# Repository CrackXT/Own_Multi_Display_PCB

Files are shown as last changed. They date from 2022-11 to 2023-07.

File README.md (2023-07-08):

# Own_Multi_Display_PCB

PCB files for Multi Display Board

# Description

This board serves as a development platform for finished devices with different display sizes.

- MiP 2,7" https://www.adafruit.com/product/4694
- TFT IPS 1,9" https://www.adafruit.com/product/5394
- TFT IPS 1,69" https://www.adafruit.com/product/5206
- TFT IPS 1,47" https://www.adafruit.com/product/5393

With a programmable status LED (RGB, SK6812-E) and an ambient light sensor (analogue, ALS-PT19) to regulate the brightness of TFT screens.

The screen, LED and ambient light sensor can be controlled via the existing Featherformat socket and the MCU used in it.

The board can be produced here (AISLER) with the files (.brd and .sch) or by any other PCB manufacturer. -> https://aisler.net/

# Serie

- .dev

# Layout

Top<br>
Multi_Display_Top

Bottom<br>
Multi_Display_Bottom

Routing/Dimensions(inch)<br>
Multi_Display_v1 0

Schematic<br>
Schematic as .pdf at the top of the page.

# License

Open hardware, use it, mod it, whatever you want, feel free...

# Thanks!

Own design and layout.

# Version - Build

v1.0 - 05.11.2022

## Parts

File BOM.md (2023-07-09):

# BOM - List

part list for Use

# sensor
1x ALS-PT19 (Anlog) https://www.digikey.de/de/products/detail/everlight-electronics-co-ltd/ALS-PT19-315C-L177-TR8/2675735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

# led
1x SK6812MINI-E 3535 https://eckstein-shop.de/OPSCO10xRGBLEDwithICSK6812SMD35284PINSK6812MINI-E-10

# resistor
1x 100kOhm 0805 https://www.reichelt.de/dk/de/smd-widerstand-0805-100-kohm-0-1-tk25-125-mw-spr-0805-100k-p123367.html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

# capacitor
2x 0,1µF 0805 https://www.reichelt.de/dk/de/smd-vielschichtkondensator-g0805-1-0-f-25v-x7r-g0805-1-0-25-p89730.html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

# socket strips
1x 1X4 https://www.reichelt.de/buchsenleiste-2-54mm-1x4-gerade-bkl-10120946-p266671.html?&trstct=pol_0&nbc=1<br>

1x 1X9<br>
- 1x 1X4 https://www.reichelt.de/buchsenleiste-2-54mm-1x4-gerade-bkl-10120946-p266671.html?&trstct=vrt_pdn&nbc=1<br>
- 1x 1X5 https://www.reichelt.de/buchsenleiste-2-54mm-1x5-gerade-bkl-10120947-p266672.html?&trstct=vrt_pdn&nbc=1<br>

3x 1X11<br>
- 3x 1X5 https://www.reichelt.de/buchsenleiste-2-54mm-1x5-gerade-bkl-10120947-p266672.html?&trstct=vrt_pdn&nbc=1<br>
- 3x 1X6 https://www.reichelt.de/buchsenleiste-2-54mm-1x6-gerade-bkl-10120948-p266673.html?&trstct=vrt_pdn&nbc=1<br>

1x 1X12 https://www.reichelt.de/buchsenleiste-2-54mm-1x12-gerade-bkl-10120951-p266676.html?&trstct=pol_1&nbc=1<br>
1x 1X16 https://www.reichelt.de/buchsenleiste-2-54mm-1x16-gerade-bkl-10120953-p266678.html?&nbc=1<br>

# button
2x APEM PHAP3363 (THT Side) https://www.conrad.de/de/p/apem-phap3363-drucktaster-12-v-dc-0-05-a-1-x-aus-ein-tastend-1-st-700310.html

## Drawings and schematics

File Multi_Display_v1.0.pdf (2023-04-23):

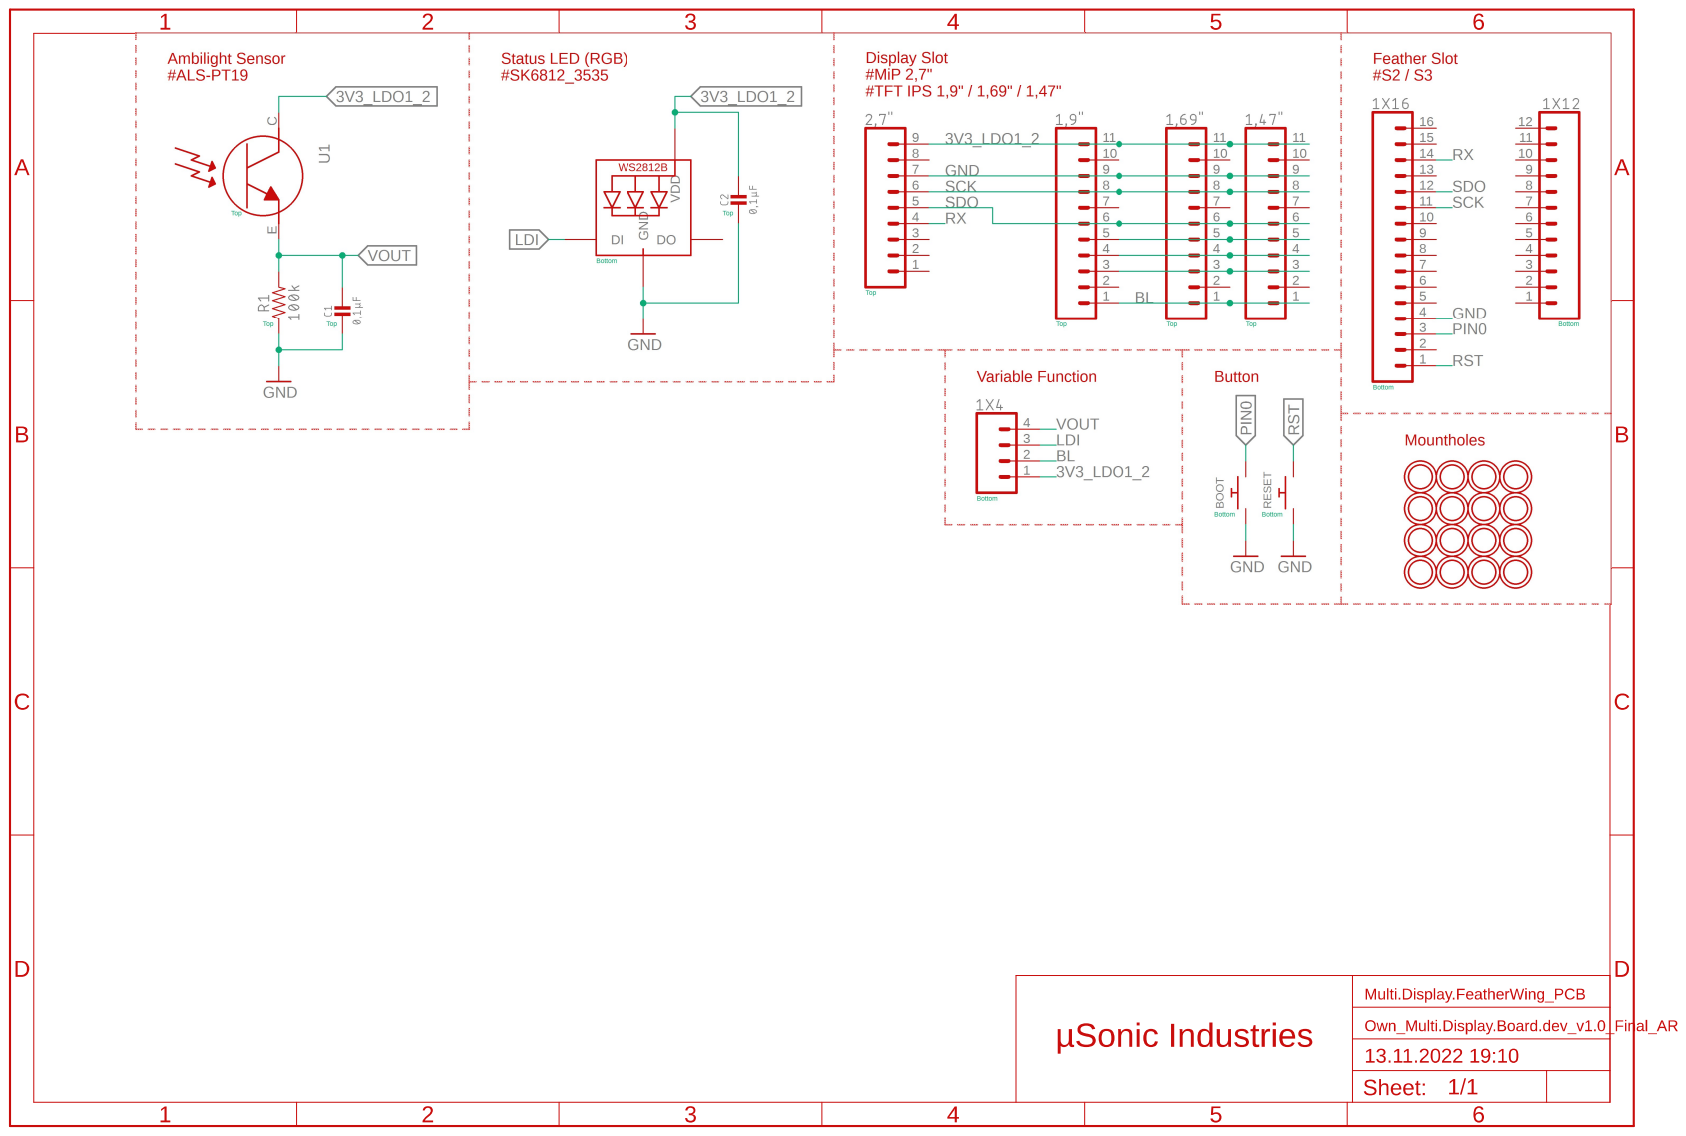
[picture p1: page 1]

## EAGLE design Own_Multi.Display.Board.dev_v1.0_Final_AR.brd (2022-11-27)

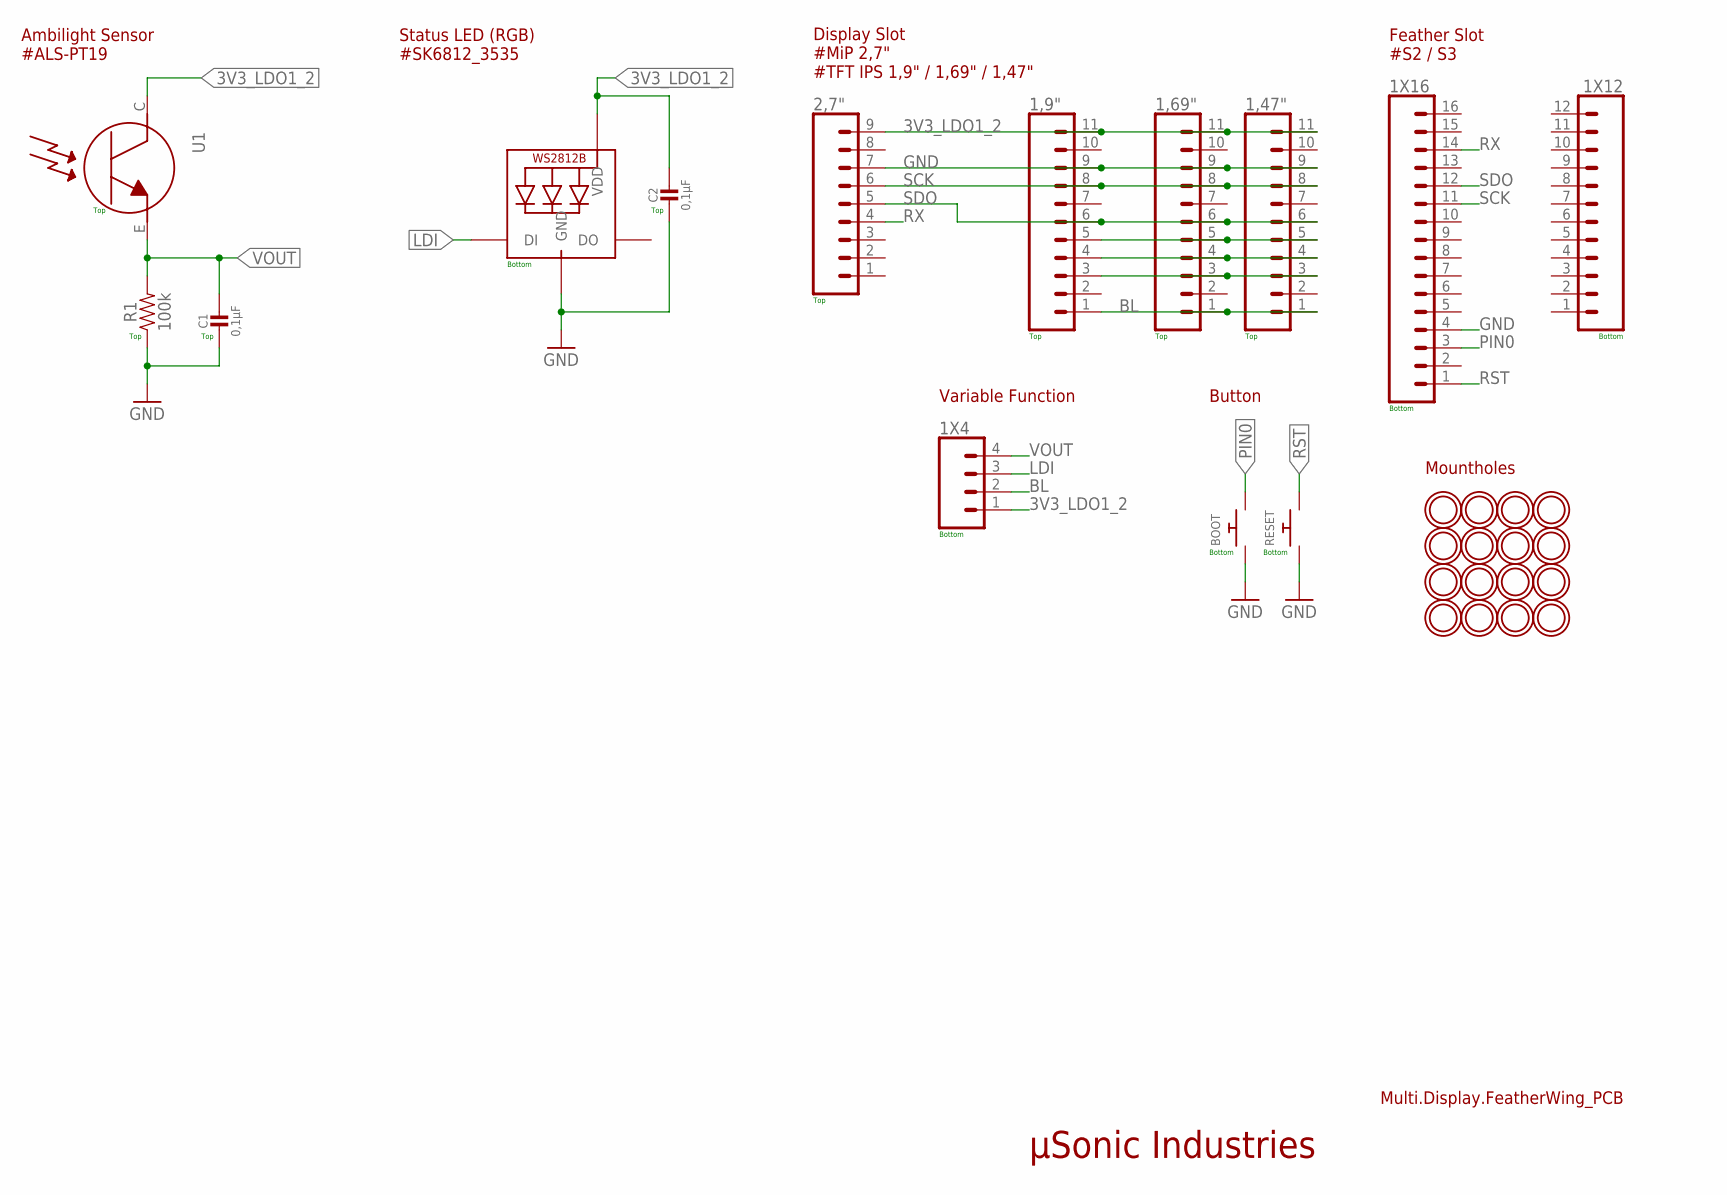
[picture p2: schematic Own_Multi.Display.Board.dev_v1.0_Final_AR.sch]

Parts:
1,9", 1,47", 1,69": CONN_111X11_NO_SILK; 1X11_NO_SILK
1X4: CONN_041X04_NO_SILK; 1X04_NO_SILK
1X12: CONN_12NO_SILK; 1X12_NO_SILK
1X16: CONN_161X16_NO_SILK; 1X16_NO_SILK
2,7": CONN_09NO_SILK; 1X09_NO_SILK
BOOT: SWITCH_PUSHBUTTONSF_OWN; OWN_TACT_PANA-EVQ
C1, C2: 0,1µF; MICROBUILDER_0805_10MGAP
LED1: MICROBUILDER_WS2812B_SK6812E; MICROBUILDER_NEO3535_REVERSE
R1: 100k; 0805
RESET: SWITCH_PUSHBUTTONSF_OWN; OWN_TACT_PANA-EVQ
U1: MICROBUILDER_LIGHT_ALS-PT19-315C; MICROBUILDER_ALS-PT19-315C
U$5, U$8, U$16, U$18, U$19, U$23, U$24, U$25, U$26, U$27, U$28, U$29, U$30, U$31, U$32, U$33: MOUNTINGHOLE2.5; MOUNTINGHOLE_2.5_PLATED

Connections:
3V3_LDO1_2: 1,9".11, 1,47".11, 1,69".11, 1X4.1, 2,7".9, C2.1, LED1.1-VDD (VDD), U1.C
BL: 1,9".1, 1,47".1, 1,69".1, 1X4.2
GND: 1,9".9, 1,47".9, 1,69".9, 1X16.4, 2,7".7, BOOT.P$1, C1.2, C2.2, LED1.3-GND (GND), R1.1, RESET.P$1
LDI: 1X4.3, LED1.4-DIN (DI)
unnamed: 1,9".5, 1,47".5, 1,69".5
unnamed: 1,9".4, 1,47".4, 1,69".4
unnamed: 1,9".3, 1,47".3, 1,69".3
PIN0: 1X16.3, BOOT.P$2
RST: 1X16.1, RESET.P$2
RX: 1X16.14, 2,7".4
SCK: 1,9".8, 1,47".8, 1,69".8, 1X16.11, 2,7".6
SDO: 1,9".6, 1,47".6, 1,69".6, 1X16.12, 2,7".5
VOUT: 1X4.4, C1.1, R1.2, U1.E

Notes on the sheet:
µSonic Industries
Multi.Display.FeatherWing_PCB
Ambilight Sensor #ALS-PT19
Mountholes
Top
Bottom
Status LED (RGB) #SK6812_3535
Display Slot #MiP 2,7" #TFT IPS 1,9" / 1,69" / 1,47"
Variable Function
Button
Feather Slot #S2 / S3

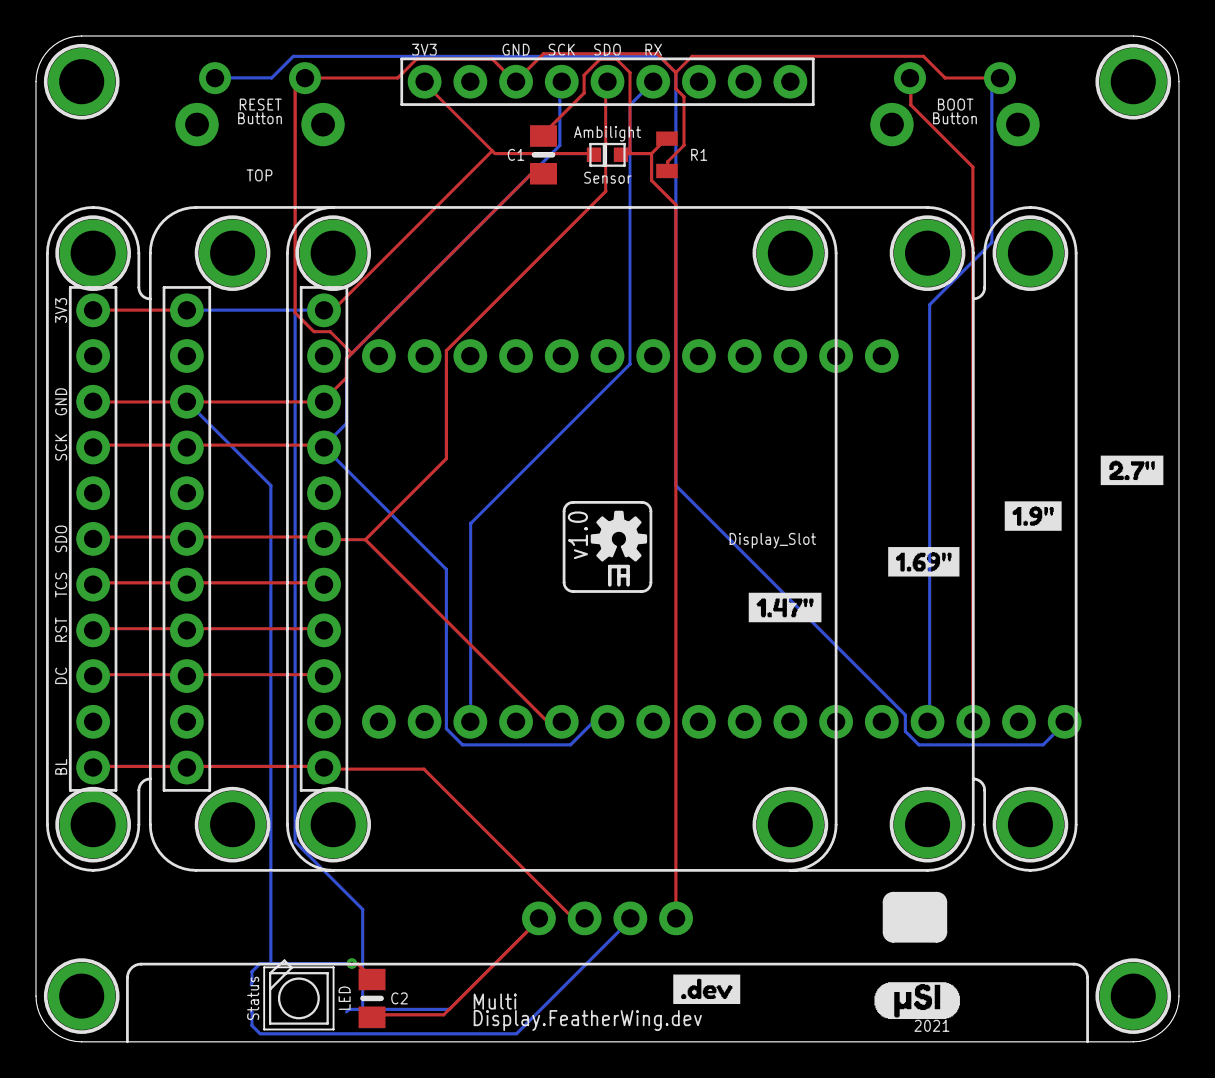
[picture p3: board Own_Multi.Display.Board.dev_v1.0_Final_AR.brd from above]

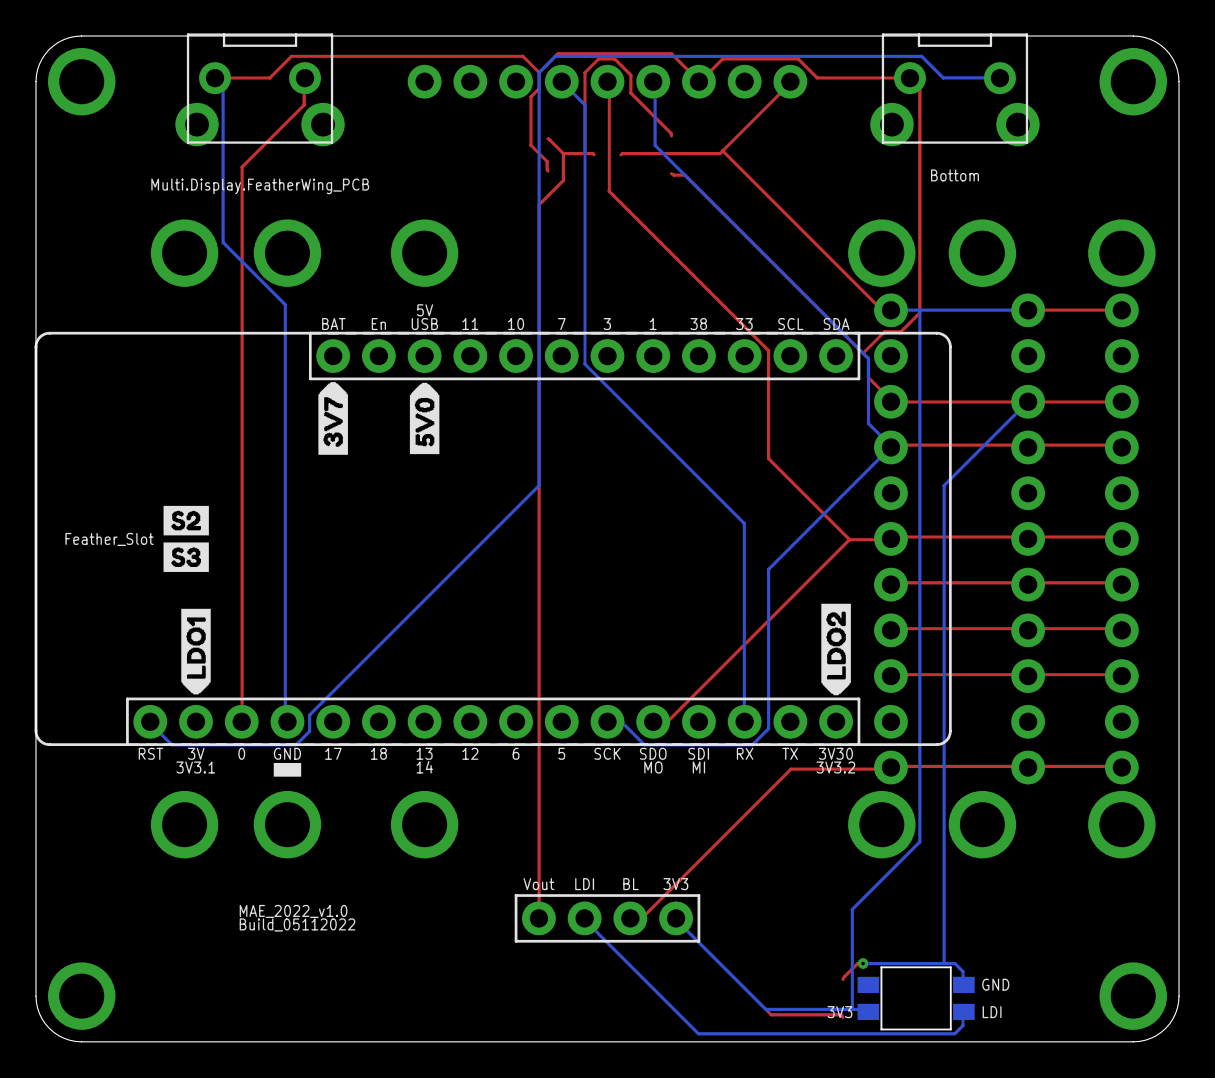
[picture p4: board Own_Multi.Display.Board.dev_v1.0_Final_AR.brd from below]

Board: 2 copper layers, 63.5 x 55.9 mm, 43 parts (8 on the bottom side), 13 nets.

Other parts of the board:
U$1: LDO15
U$4: OSHW-LOGO-S
U$6: #DEV15
U$7: LDO26
U$9: 3V72
U$10: 5V03
U$15: S212
U$17: S313
U$22: #SI0
U$34: 1#9#11
U$35: 1#69#10
U$36: 1#47#9
U$37: 2#7#12

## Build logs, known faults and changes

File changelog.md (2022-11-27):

# Version - Build
v1.0 - 05.11.2022
- First Release

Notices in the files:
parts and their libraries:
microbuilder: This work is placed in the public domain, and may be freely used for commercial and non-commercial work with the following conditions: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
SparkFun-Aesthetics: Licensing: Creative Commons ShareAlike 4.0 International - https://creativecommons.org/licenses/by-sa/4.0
